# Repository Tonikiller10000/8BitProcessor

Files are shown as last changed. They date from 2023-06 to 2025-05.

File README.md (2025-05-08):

# 8Bit Computer

### Description:
This is a series of modules(3 at the moment) witch make an functional 8 bit processor for educational purposes: 
- [ALU](https://github.com/Tonikiller10000/8BitProcessor/tree/main/Processor_ALU_V1.0)
- [Display Register](https://github.com/Tonikiller10000/8BitProcessor/tree/main/DisplayRegister)
- [CLK Pulse Generator](https://github.com/Tonikiller10000/8BitProcessor/tree/main/ClkPulseGenerator)

> [!TIP]
> By clicking on a module link, you can read it\`s speciffic documentation.

<table>
  <tr>
    <td>ALU</td>
    <td>Display Register</td>
    <td>CLK Pulse Generator</td>
  </tr>
  <tr>
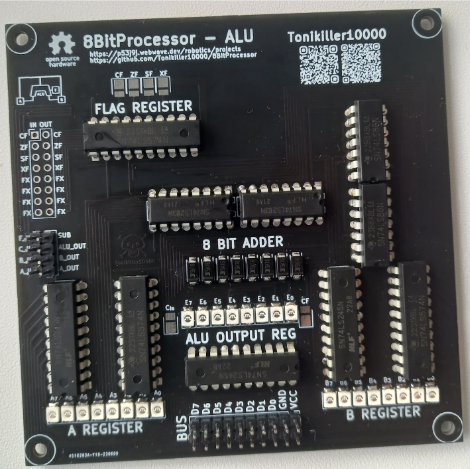
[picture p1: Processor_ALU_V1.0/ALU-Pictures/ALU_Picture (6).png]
    <td></td>
    <td></td>
    <td></td>
  </tr>
 </table>

Links:
BenEater YouTube: https://www.youtube.com/beneater 
BenEater WebSite: https://eater.net/8bit   
GitHub: https://github.com/Tonikiller10000/8BitProcessor 
JLC: https://jlcpcb.com/ 

Photo:....


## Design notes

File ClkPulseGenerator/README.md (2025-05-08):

# 8Bit Computer/ Clock Pulse Generator

### Description:
This board generates 0-5V square wave CLK pulses for my 8Bit processor/computer and has an tactile switch to change between it\`s 2 states:
- astable mode: generate CLK pulses at variable speed by the potentiometer value from one pulse at every 1,2 seconds to an pulse at each every few milisecondes (The potentiometer and capacitor values should be changed)
- monostable mode: send debounced CLK signals at the push of a button

<table>
  <tr>
    <td></td>
    <td>
        ### PINS:
        - VCC - 5V input
        - GND - 0V input
        - GND - 0V input (optional)
        - HLT - input, connect to 5V to stop sending CLK pulses, and to <b>0V for normal operration</b>
        - CLK - CLK pulse generator output
        - CLK - inverted CLK pulse generator output   //clk bar</td>
  </tr>
 </table>

<table>
  <tr>
    <td></td>
    <td></td>
    <td></td>
    <td></td>
  </tr>
 </table>

<table>
  <tr>
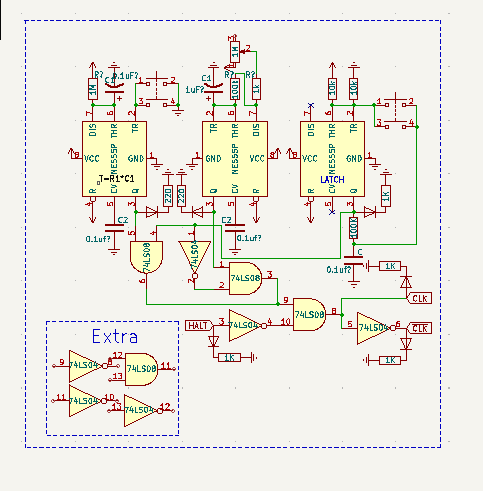
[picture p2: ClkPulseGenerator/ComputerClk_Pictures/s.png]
    <td></td>
    <td>
        This is the Ben Eater schematic made by me.
         Link to Ben Eater breadboard CKL pulse generator:
         https://youtu.be/SmQ5K7UQPMM?si=6SvCCjpXzhz8pTbt
    </td widht=40%>
  </tr>
 </table>

### Results:
The potentiometer has to varry the clk speed from 1,2Hz to few KHz witch need it and the capacitors values to be changed. (need further testing)

Datasheets:
- NE555: https://pdf1.alldatasheet.com/datasheet-pdf/view/471200/STMICROELECTRONICS/NE555.html
- 74LS00 (4x NAND gate): https://pdf1.alldatasheet.com/datasheet-pdf/view/51021/FAIRCHILD/74LS00.html

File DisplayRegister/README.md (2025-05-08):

# 8Bit Computer/ Display Register

### Description:
This board is an 8 bit register witch can display it\`s value on an 4 digit 7 segment display using the multiplexing process. It has 8 led\`s to display it\s contents in binnary, an 2 position switch to help you select between 2 programable modes (HEX, DEC, SGN_DEC, ...) and a potentiometer to increase/decrease the multiplexing speed to help understanding of the multiplexing principle. 

<table>
  <tr>
    <td></td>
    <td></td>
    <td></td>
  </tr>
 </table>
Schematic:


### How it works
The 8 bit bus is connected to the 74LS574 8 bit register witch outputs it\`s value to 8 address pins of the EEPROM  and to the led\`s to show it\`s value.
Another 2 EEPROM address pins are used to select one of the 4 digits value, and the rest are connected to switches to select the displaing mode (EX. negative numbers) or tied to 0V or 5V if not used.
The display is connected to an demultiplexer(74LS138) witch selects witch digit to be displayed, and the demultiplexer with the eeprom are connected to a binnary counter made with 2 JK latches(74LS76) witch recive clk pulses from an NE555 timer IC. The clk speed can be changed from the potentiometer to admire the multiplexing effect.




### Results:
Power it to 5V, put a value on the bus, store it by setting the D_in pin HIGH and every thing should work.
The project is working, but the frequency interval of the potentiometer wasn\`t verry visible, so the capacitors and resistors values should be changed. 

Datasheets:
- 74LS574 (8 bit register): https://pdf1.alldatasheet.com/datasheet-pdf/view/51086/FAIRCHILD/74LS574.html
- AT28C64 (8K x 8 EERPOM): https://pdf1.alldatasheet.com/datasheet-pdf/view/157137/ATMEL/AT28C64.html
- AT28C256 (32K x 8 EERPOM): https://ww1.microchip.com/downloads/en/DeviceDoc/doc0006.pdf
- 74LS138 ( 3 -> 8 demultiplexer ): https://pdf1.alldatasheet.com/datasheet-pdf/view/51039/FAIRCHILD/74LS138.html
- 74LS76 (JK Flip Flop): https://pdf1.alldatasheet.com/datasheet-pdf/view/12663/ONSEMI/74LS76.html
- NE555: https://pdf1.alldatasheet.com/datasheet-pdf/view/471200/STMICROELECTRONICS/NE555.html

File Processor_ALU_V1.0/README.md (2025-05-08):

# 8Bit Computer/ Processor_ALU

<table>
  <tr>
    <td>

### Description:
This board is used for addition and substraction. It is formed of 2 registers A and B, the actual ALU (Arithmetic and Logic Unit), and the Flag Register witch has a Carry flag, a Zero flag, a Sign flag and 5 other empty, free to use for other stuff, flags. 
    </td>
    <td></td>
  </tr>
 </table>
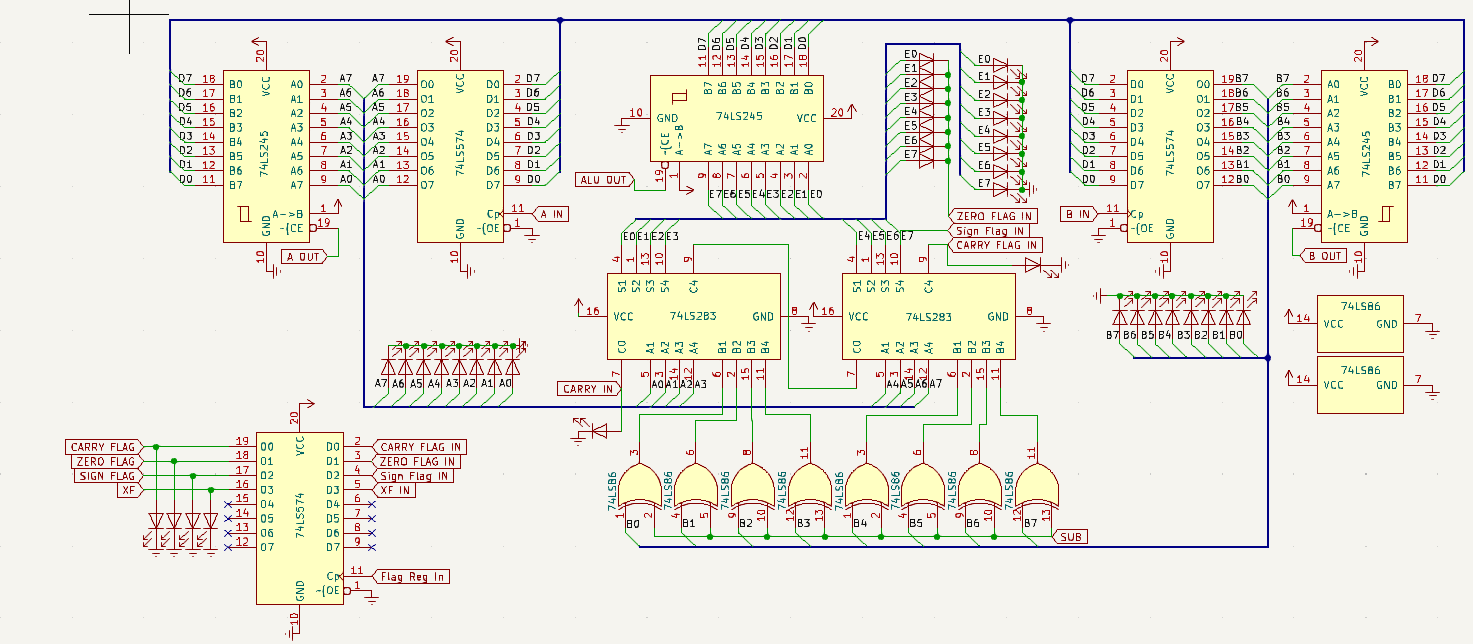
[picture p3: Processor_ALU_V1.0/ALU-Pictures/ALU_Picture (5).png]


### How to use:
1. Put values in the A and B register by putting a value on the bus and setting the A_IN or B_IN pin HIGH.
2. By setting the SUB pin LOW (default), the ALU adds the A Reg value and the B reg Value upt to 255, 
after witch the carry flag gets activated and the result remain the difference between the result and 256.
EX. 199 + 69 = 22(+C)
When the SUB pin is pulled HIGH, the ALU returns the difference between A register value and B register value.
3. The carry input can be changed from the C_IN pin.
4. By setting the F_IN pin HIGH, the flag values are saved in the Flag register. 
5. The result of the ALU can be outputed in the bus by putting the ALU_OUT pin HIGH.
The ALU result can be put back in the A or B registers and be used for other operations.

<table>
  <tr>
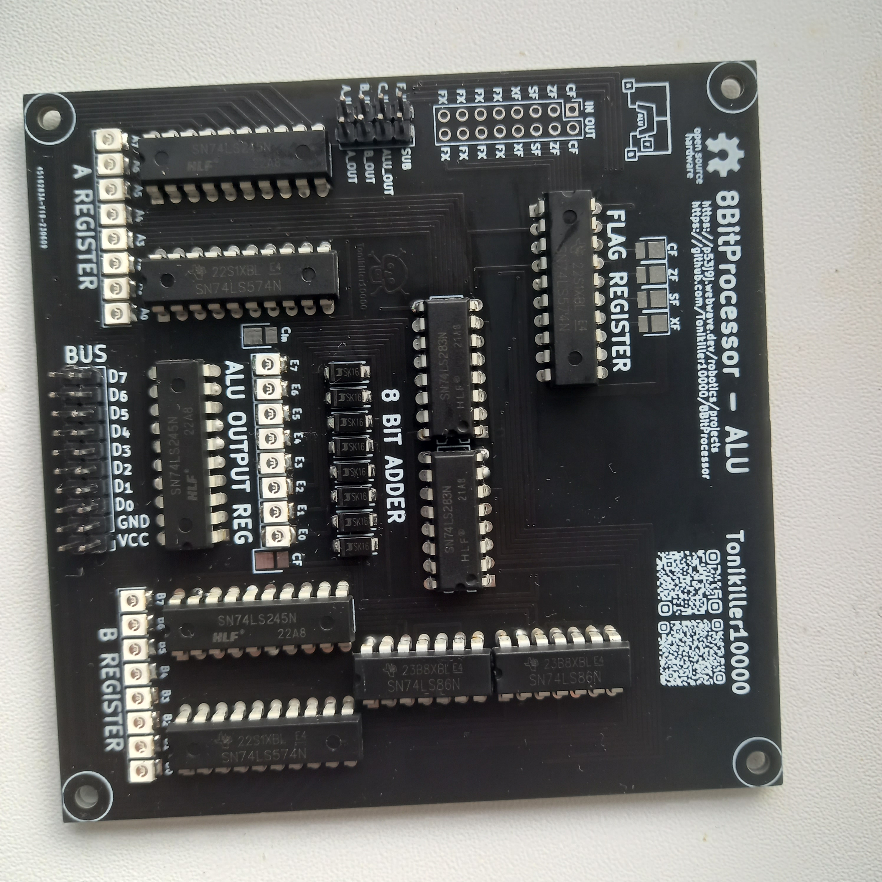
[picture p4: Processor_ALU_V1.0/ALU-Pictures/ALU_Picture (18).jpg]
    <td></td>
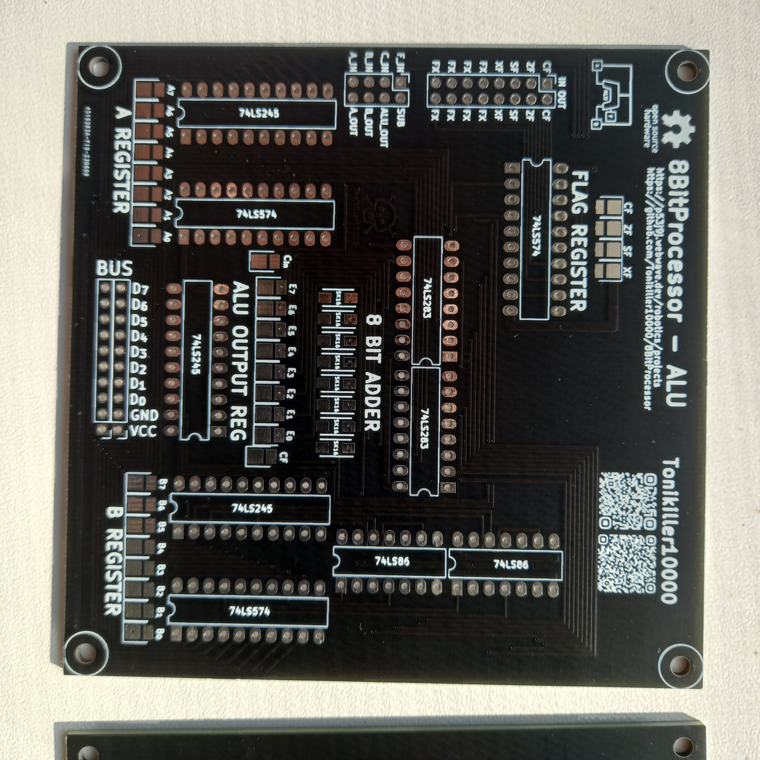
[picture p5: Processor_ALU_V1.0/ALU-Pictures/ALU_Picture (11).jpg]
    <td></td>
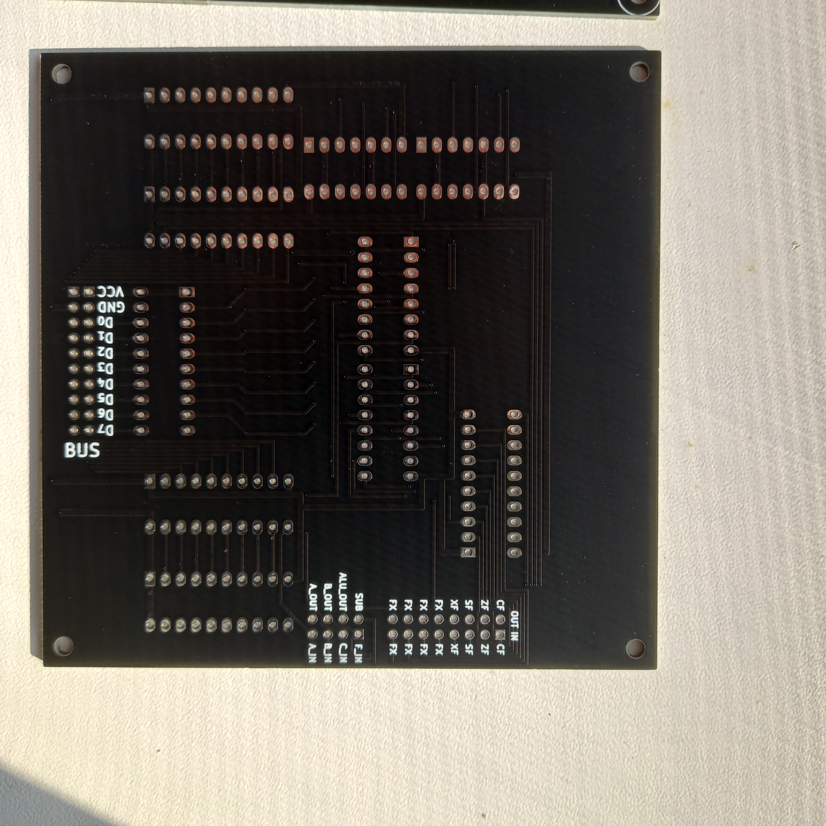
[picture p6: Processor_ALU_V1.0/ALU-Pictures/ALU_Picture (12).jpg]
    <td></td>
  </tr>
 </table>

### How it wworks
The A and B registers are dmade with an 8 bit register with output always enabled and an tristate buffer to connect the register to the buss. By making it this way, you can always see the internal value on the led\`s and the register values are continuousely sent to the ALU. The 8 bit adder is made of 2x 4bit adders, and the substraction is made by inverting the bits values of the B register. By inverting the B register bits values, the value in the B register is negate and by adding the negative of a number, you can substract it: 
<br><b> 3 + (-2) = 1 </b><br>
The inversion of the B register bits is made with an NAND gate witch can be made as an enable pin.

### Mentions:
- All the pins should have an pull-down resistors to assure the default mode opperation
- By not using resistors for the led\`s thinking that the 74LSx series IC\`s has integrated resistors, the led\`s are to brigth, and their intensity changes depending on how many led\`s are ligthned up. ( https://github.com/Tonikiller10000/8BitProcessor/blob/main/Processor_ALU_V1.0/ALU-Pictures/ALU_Picture%20(17).jpg )
- This is the first version, Future versions will come in the next version of the processor. ( https://github.com/Tonikiller10000/8BitProcessor/tree/main )
- It can make more complex opperations like, multiplication(repeated addition), division(repeated substraction) and rise to power(repeated multiplication) with the rigth software 
- The 74LS574 IC is the same as the 74LS374 IC but has a different pinnout witch makes it easier to use
- The 74LS573 and 74LS373 are the same as the 74LS574 and 74LS374, but the latching time happends on the entire length of the HIGH clk pulse.

Datasheets:
- 74LS245 (Tri-state buffer): https://pdf1.alldatasheet.com/datasheet-pdf/view/51057/FAIRCHILD/74LS245.html
- 74LS574 (8 bit register): https://pdf1.alldatasheet.com/datasheet-pdf/view/51086/FAIRCHILD/74LS574.html
- 74LS283 (4 bit adder): https://pdf1.alldatasheet.com/datasheet-pdf/view/8069/NSC/74LS283.html
- 74LS86 (4x XOR gate): https://pdf1.alldatasheet.com/datasheet-pdf/view/51095/FAIRCHILD/74LS86.html

74LS00: https://pdf1.alldatasheet.com/datasheet-pdf/view/51021/FAIRCHILD/74LS00.html 
74LS283: https://pdf1.alldatasheet.com/datasheet-pdf/view/1718878/ETC1/74LS283N.htm
74LS374: https://pdf1.alldatasheet.com/datasheet-pdf/view/51080/FAIRCHILD/74LS374.html 
74LS245: https://pdf1.alldatasheet.com/datasheet-pdf/view/12640/ONSEMI/74LS245.html

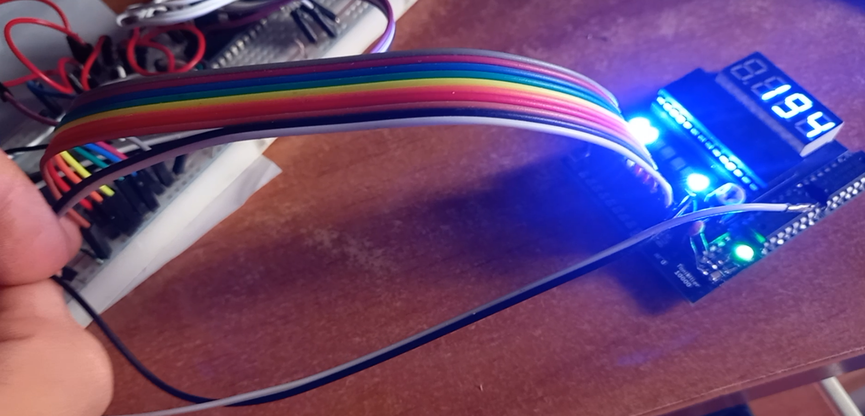
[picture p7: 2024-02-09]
DisplayRegister/DisplayRegister_Pictures/pic2.png

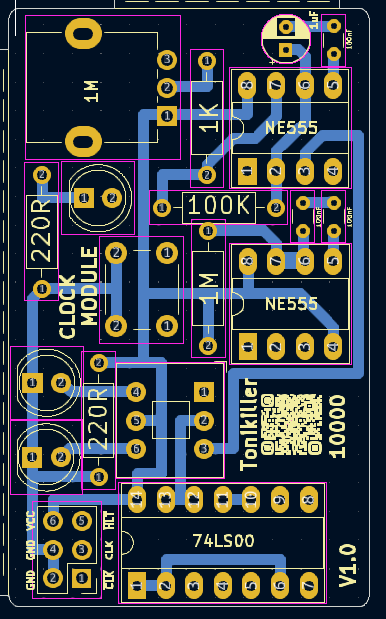
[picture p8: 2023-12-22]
ClkPulseGenerator/ComputerClk_Pictures/s4.png

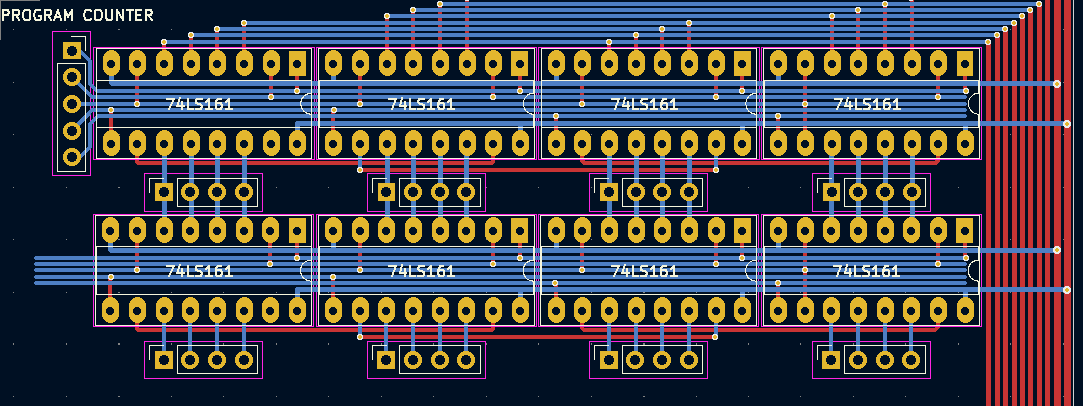
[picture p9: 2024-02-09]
ProcessorPhotos/{F923B022-E4A4-4F73-8869-FA77D3219F20}.png

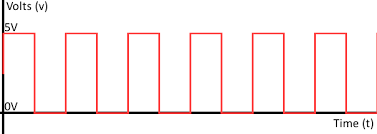
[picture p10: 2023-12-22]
ClkPulseGenerator/ComputerClk_Pictures/d1.png

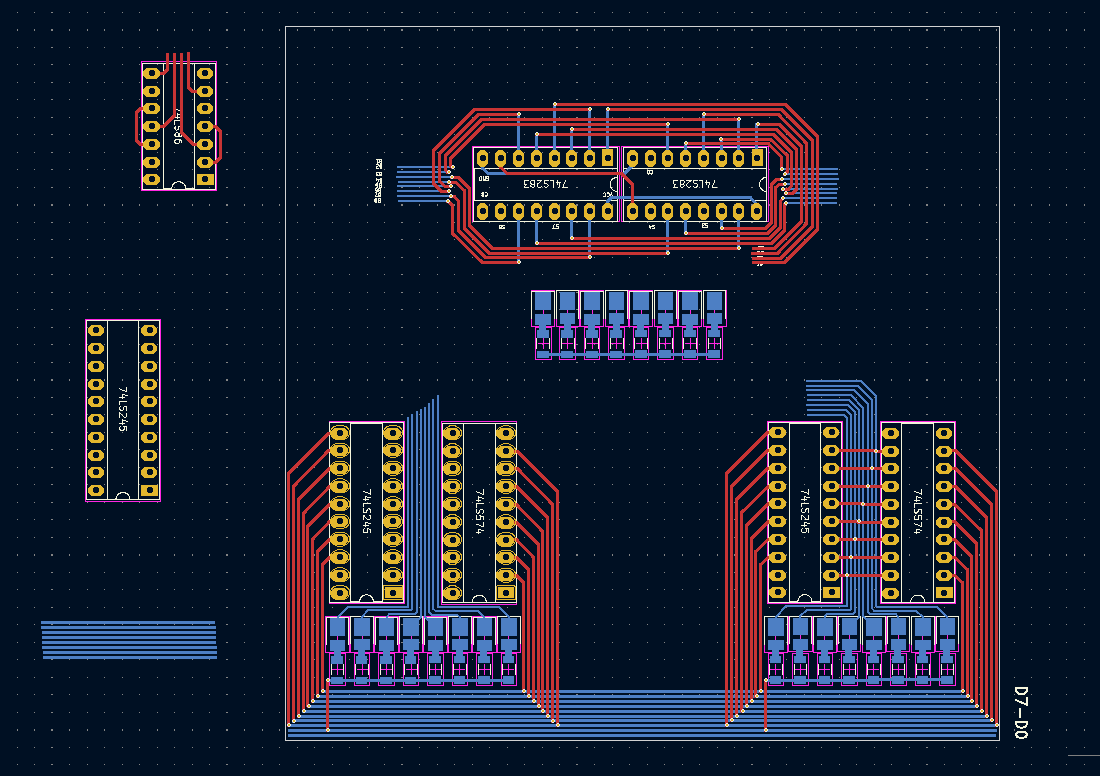
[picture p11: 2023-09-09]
Processor_ALU_V1.0/ALU-Pictures/ALU_Picture (3).png

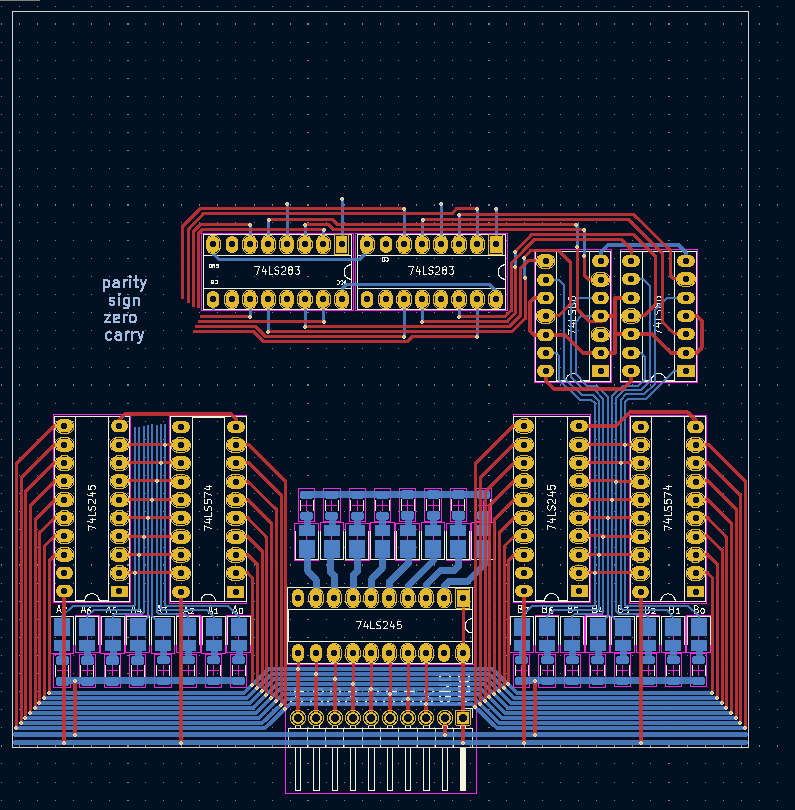
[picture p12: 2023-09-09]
Processor_ALU_V1.0/ALU-Pictures/ALU_Picture (4).png

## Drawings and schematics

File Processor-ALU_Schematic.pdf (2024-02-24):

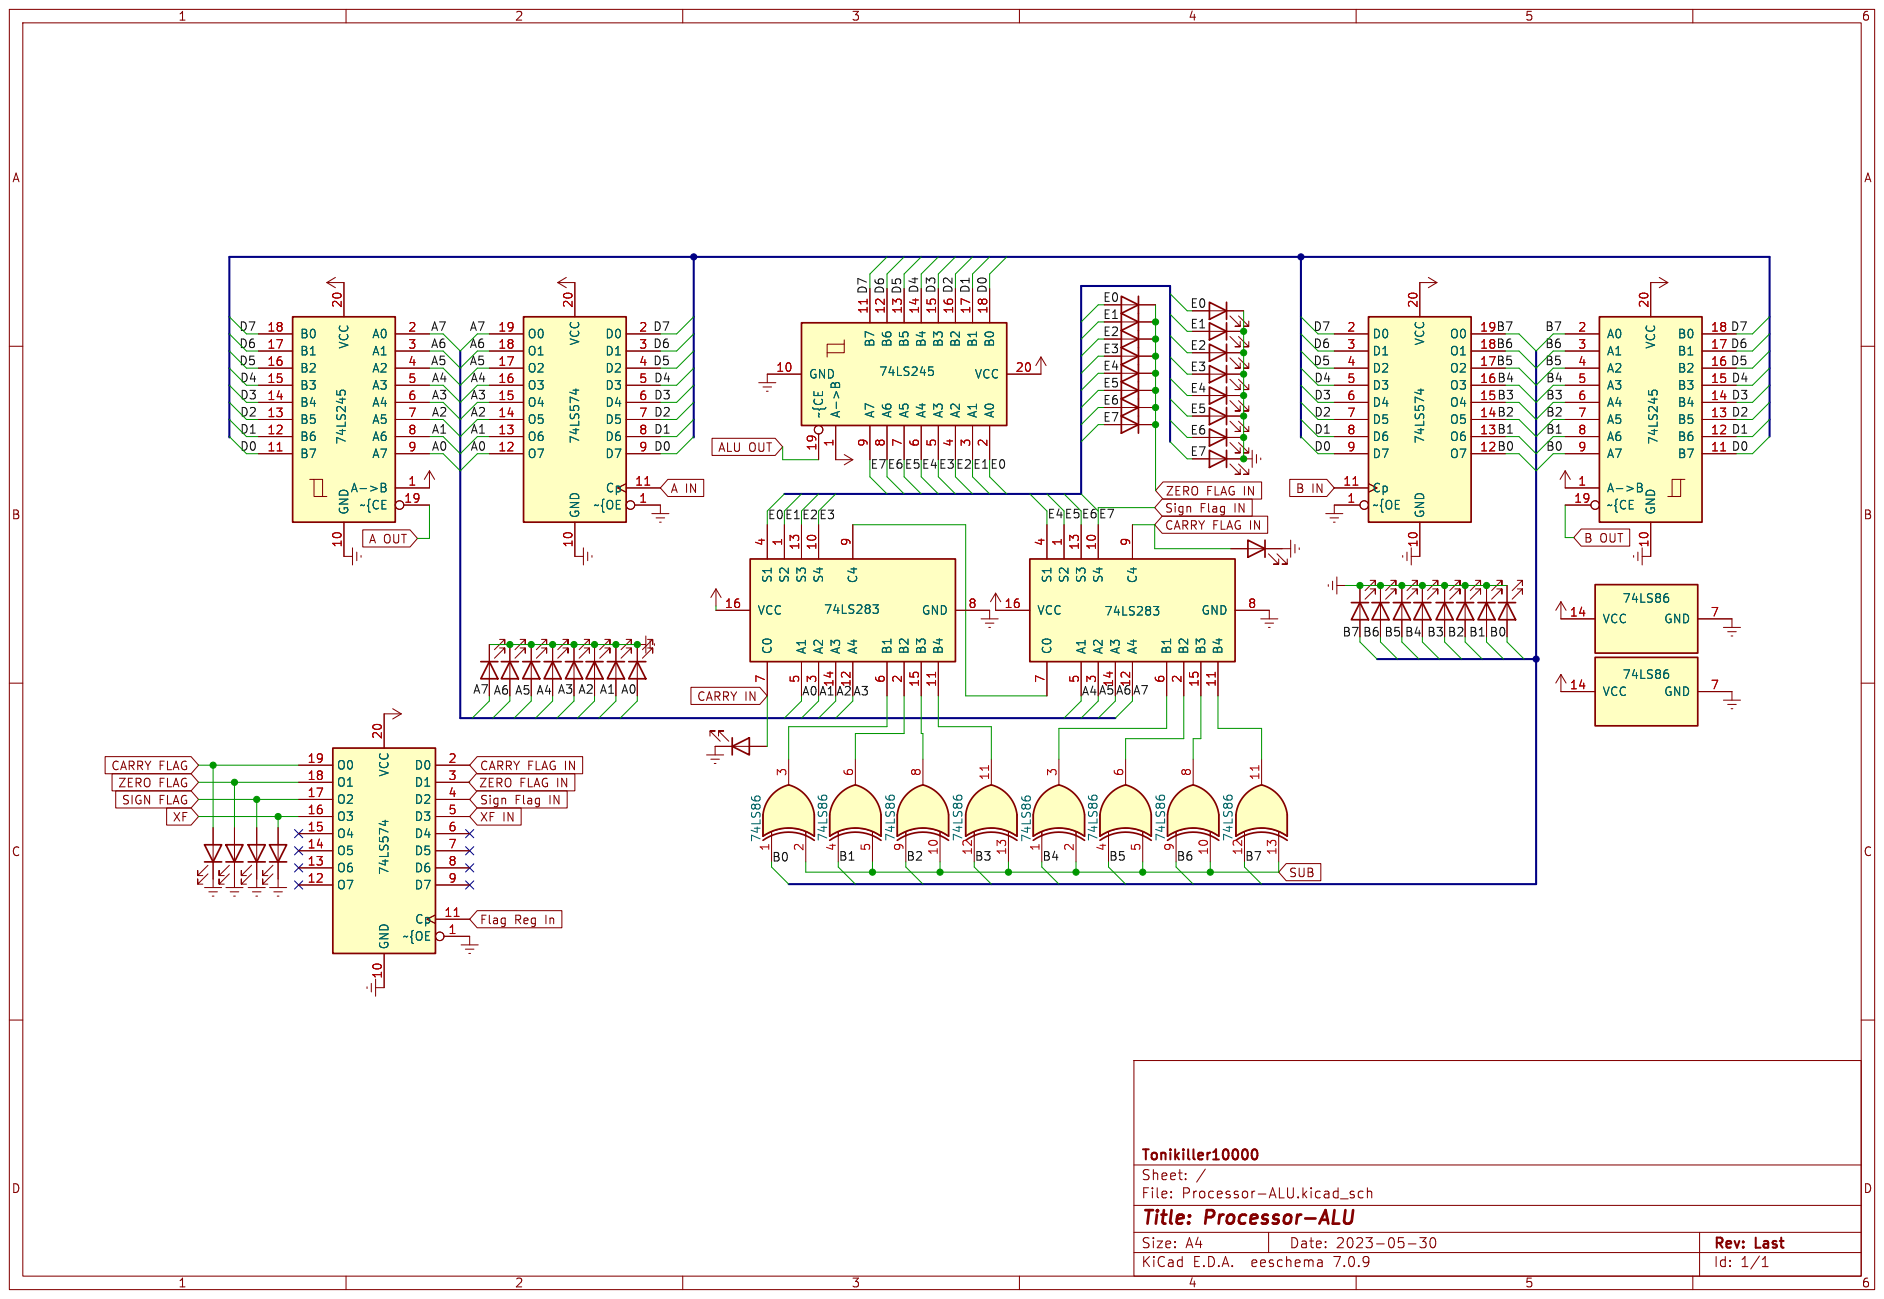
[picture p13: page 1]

1 GND 10 B7 11 B6 12 B5 13 B4 14 B3 15 B2 16 B1 17 B0 18 ~{CE 19 A0
SUB CARRY FLAG IN

Flag Reg In XF

Id: 1/1 Title: Processor-ALU

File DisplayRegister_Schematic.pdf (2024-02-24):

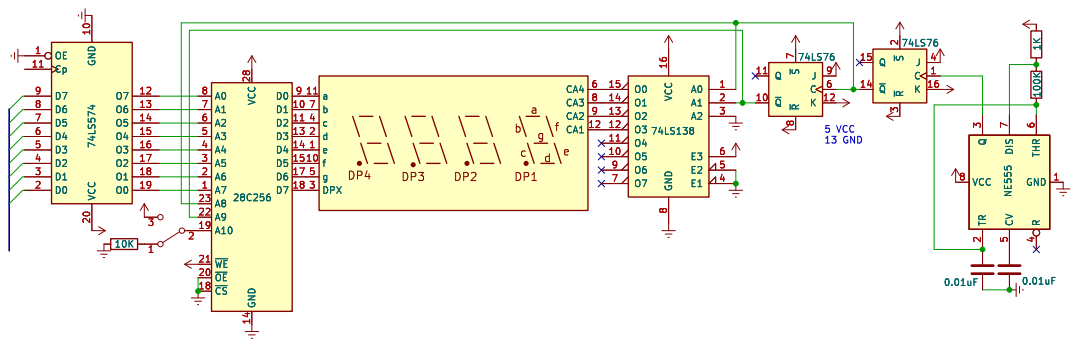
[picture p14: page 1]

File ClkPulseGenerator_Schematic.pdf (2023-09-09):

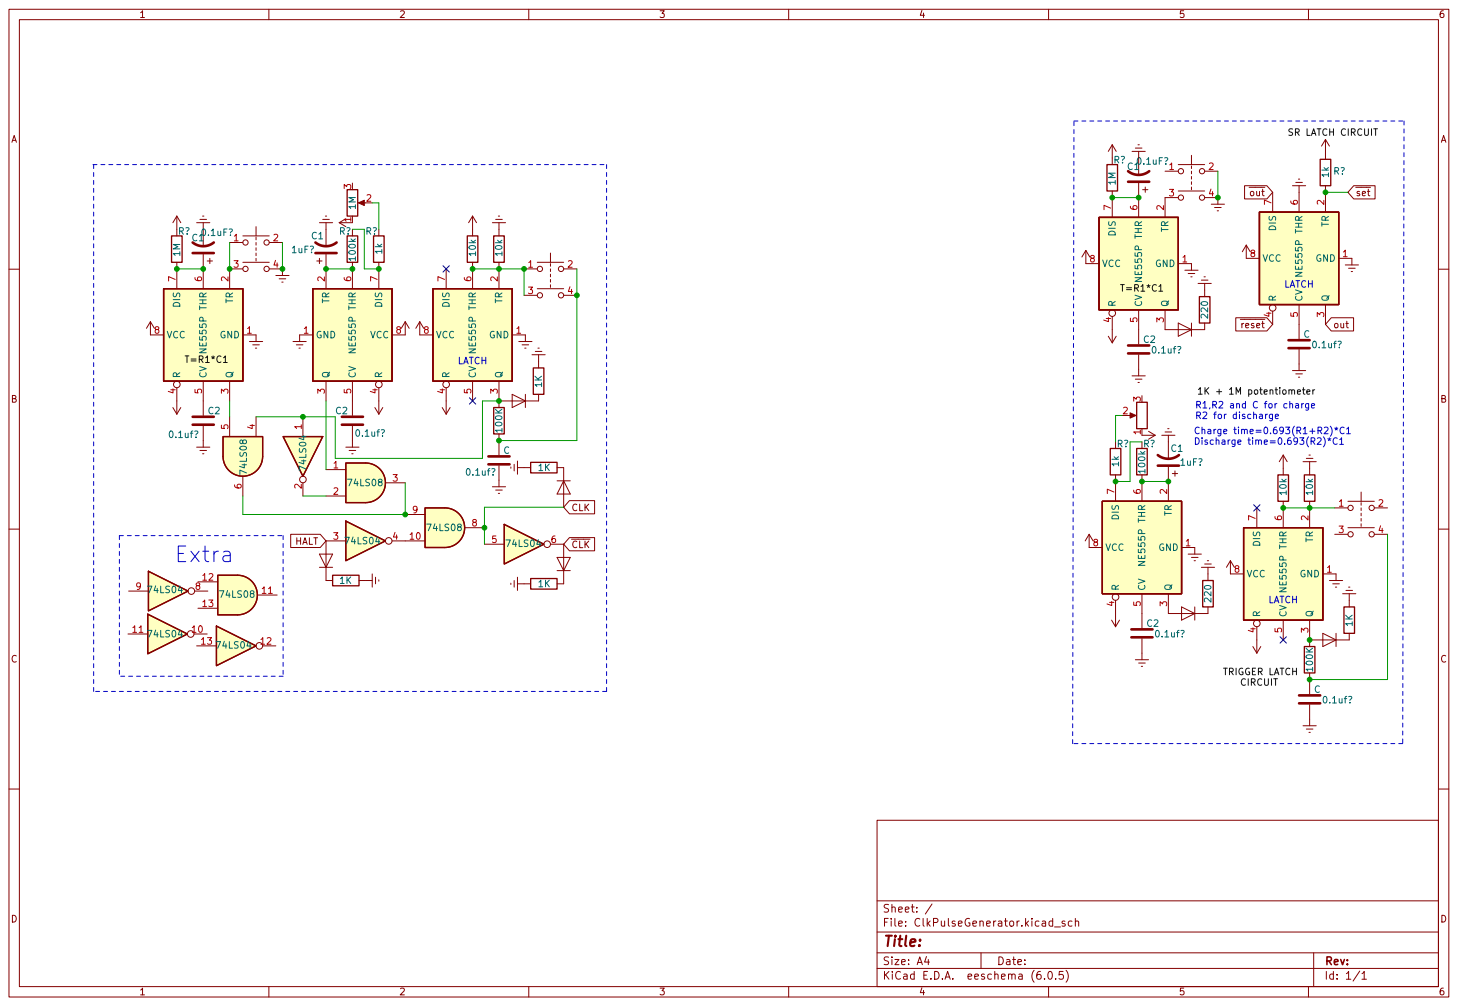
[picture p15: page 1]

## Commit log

2023-09-09 8BitProcessor_Update1
    uploading files
    [Processor-ALU-B_Cu.gbr, Processor-ALU-B_Mask.gbr, Processor-ALU-B_Paste.gbr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]
2023-09-09 update2
    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
    [ClkPulseGenerator.kicad_pcb, ClkPulseGenerator.kicad_sch]
2023-09-09 FirstCompleteUpdate
    All the starting files has been updated.
    [DisplayRegister.kicad_pcb, DisplayRegister.kicad_sch]
